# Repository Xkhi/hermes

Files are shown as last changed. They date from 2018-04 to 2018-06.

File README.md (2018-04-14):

# Project Hermes 

Property of [Waseda University](https://www.waseda.jp/top/en) [Graduate School of Creative Science and Engineering](http://www.cse.sci.waseda.ac.jp/en/).
Developed by [Javier Alvarez](mailto:javier.alvarez@akane.waseda.jp).

Project Hermes is a communication hub for sensors, developed specifically for WU's Sensor Team in Sugano Lab. 

## Status
- [x] Requirements definition
- [x] Conceptual design
- [x] Schematics
- [x] PCB
- [ ] Manufacture
- [ ] Programming

### Status Overview
The project has finished establishing requirements, concepts and schematics, and the PCB layout design has finished. The manufacturing process will begin soon.

## Specifications
The aim for the device are listed as follows:

* Act as a communication HUB for 5 sensors (I<sup>2</sup>C)
* Provide a network for communication between devices by a common bus (I<sup>2</sup>C)
* Power input 5V~12V

## Contact

For questions regarding the device:

* Design: [Javier Alvarez](mailto:javier.alvarez@akane.waseda.jp)
* Ownership: [Alexander Schmitz](mailto:schmitz.alexander@gmail.com), [Tito Tomo](mailto:tito@toki.waseda.jp), [Sophon Somlor](mailto:sophon@sugano.mech.waseda.ac.jp)

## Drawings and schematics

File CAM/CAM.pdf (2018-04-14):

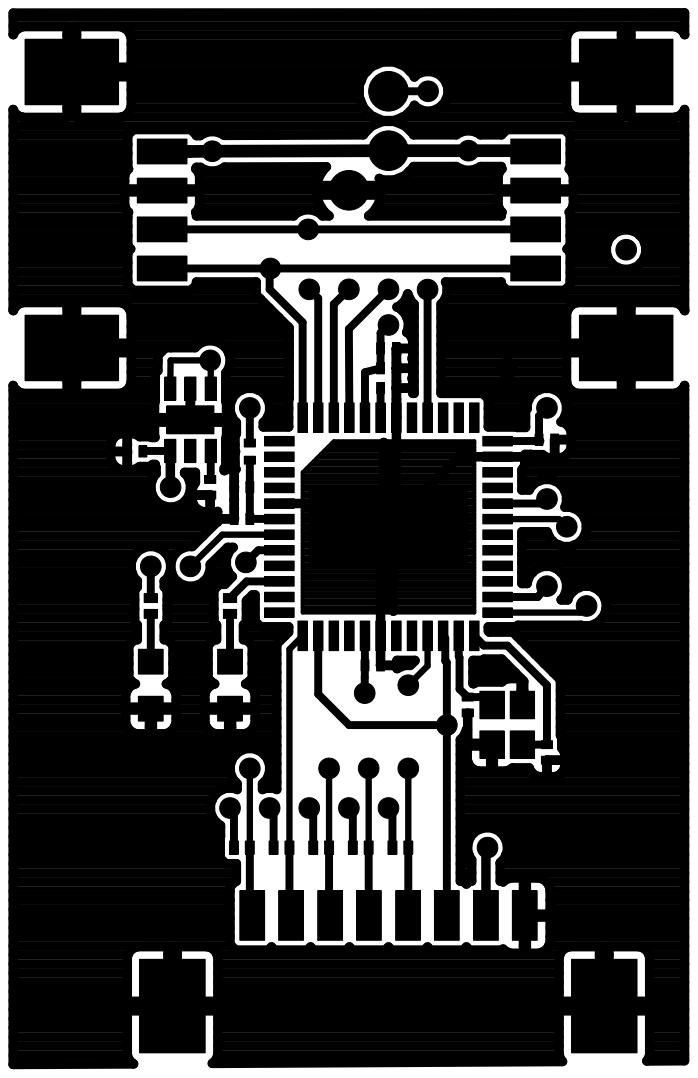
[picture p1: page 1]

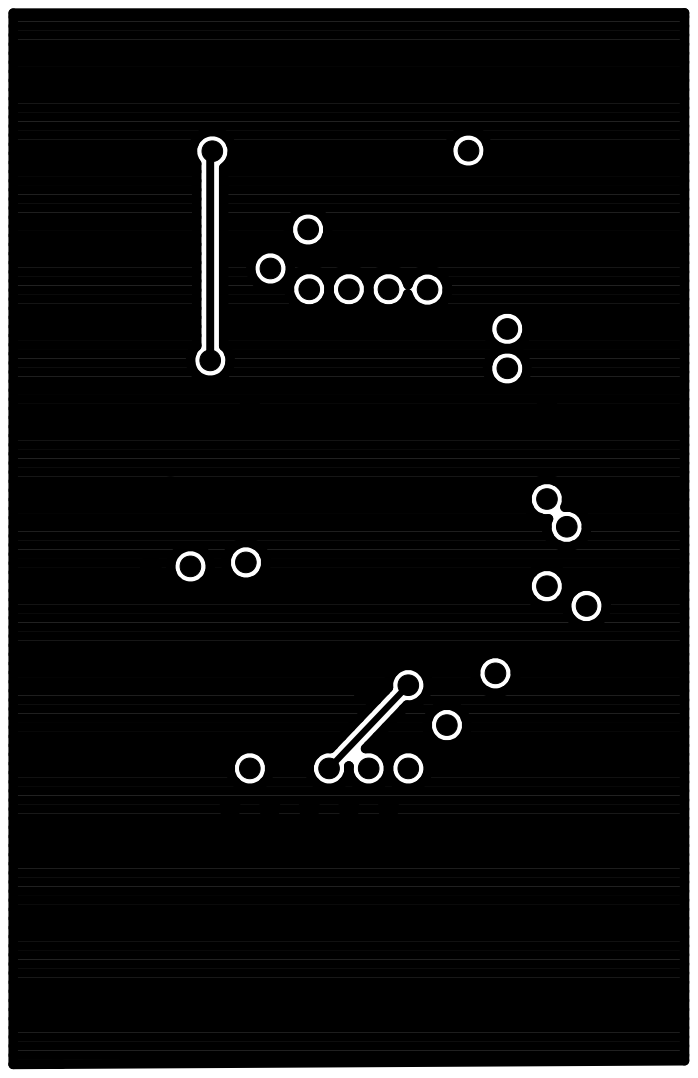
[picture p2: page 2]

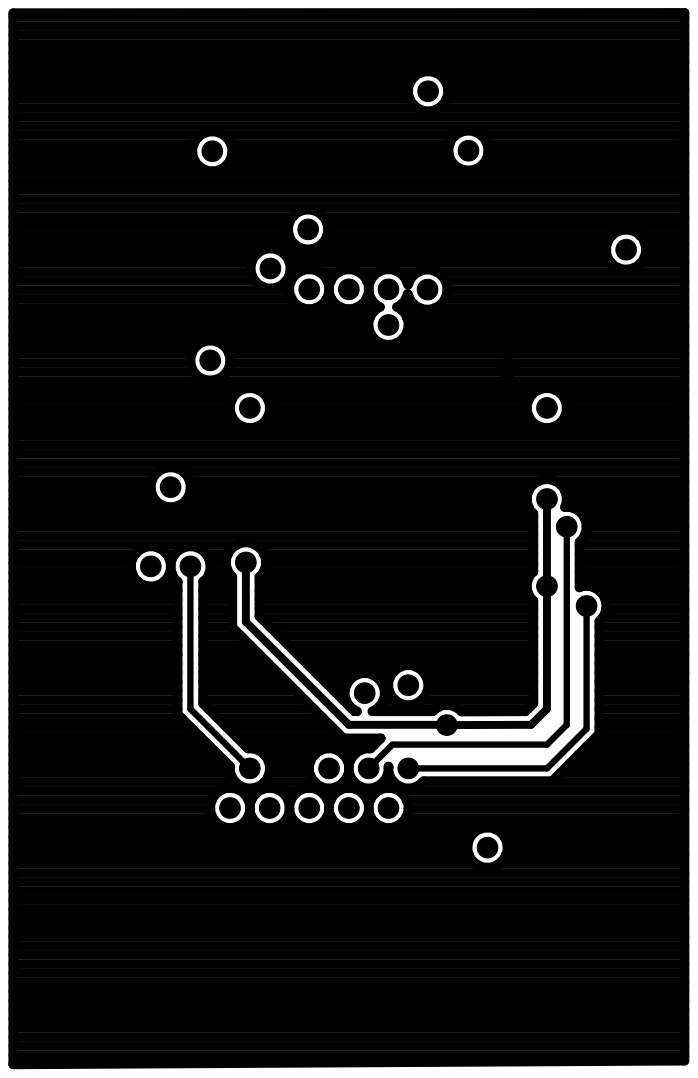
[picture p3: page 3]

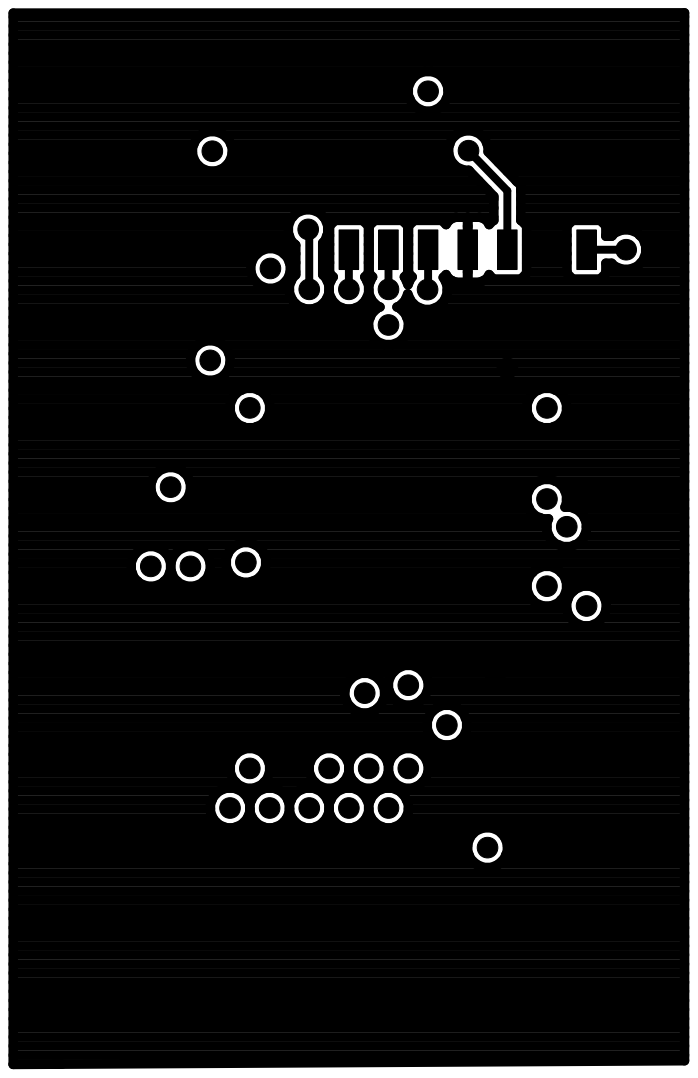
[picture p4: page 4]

# 3V3 GND

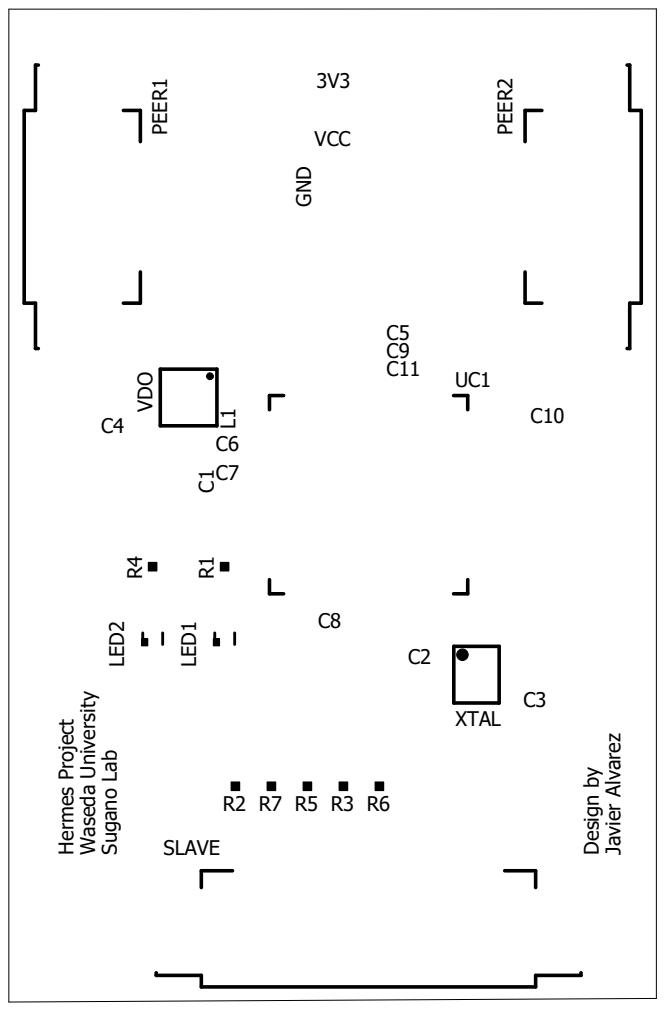
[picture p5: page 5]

Hermes Project Waseda University Sugano Lab Design by Javier Alvarez C1

PIN3 PIN4 PIN5 PIN6 PIN1 PIN2

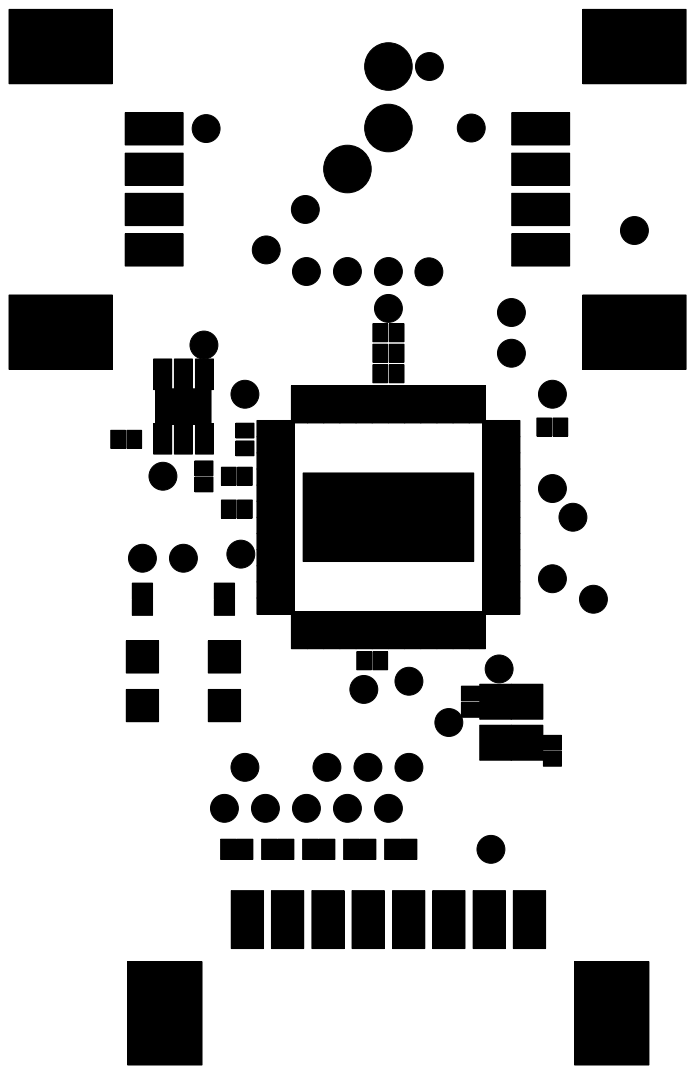
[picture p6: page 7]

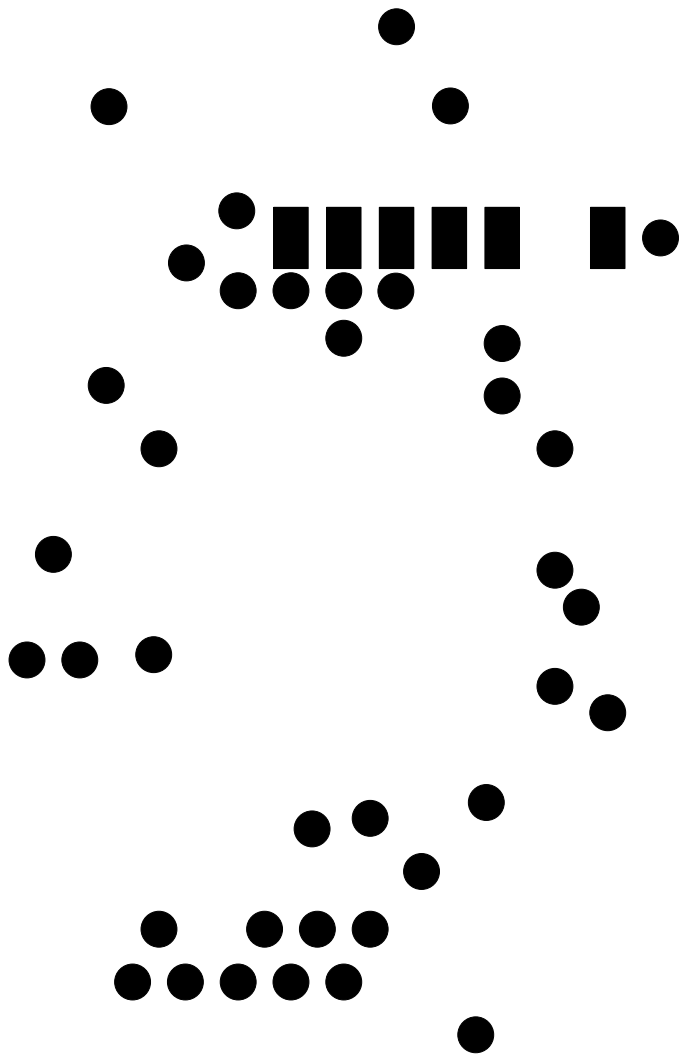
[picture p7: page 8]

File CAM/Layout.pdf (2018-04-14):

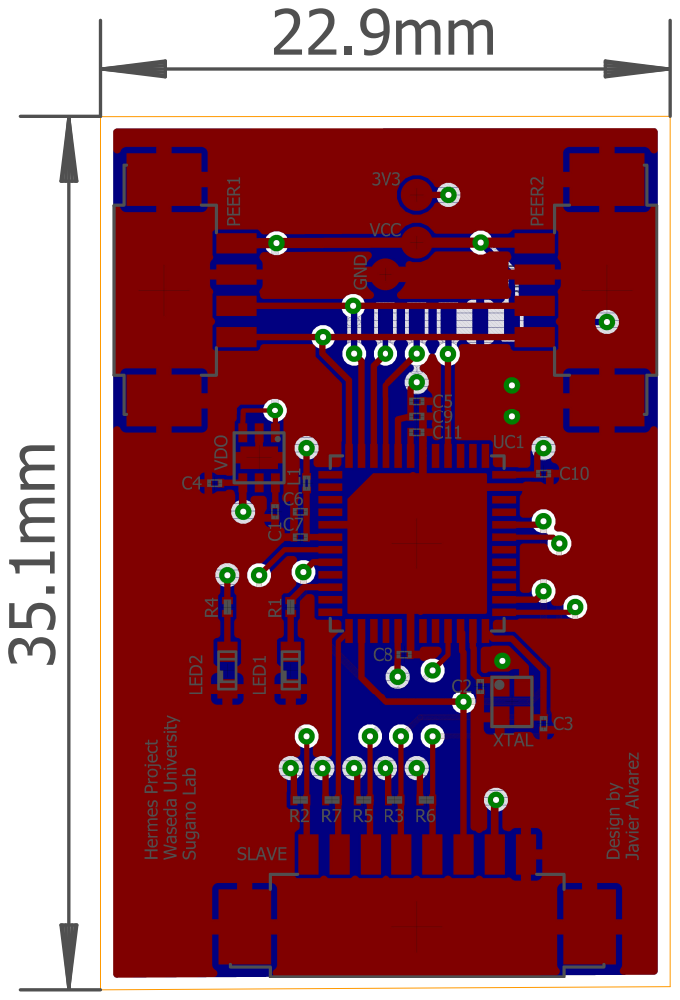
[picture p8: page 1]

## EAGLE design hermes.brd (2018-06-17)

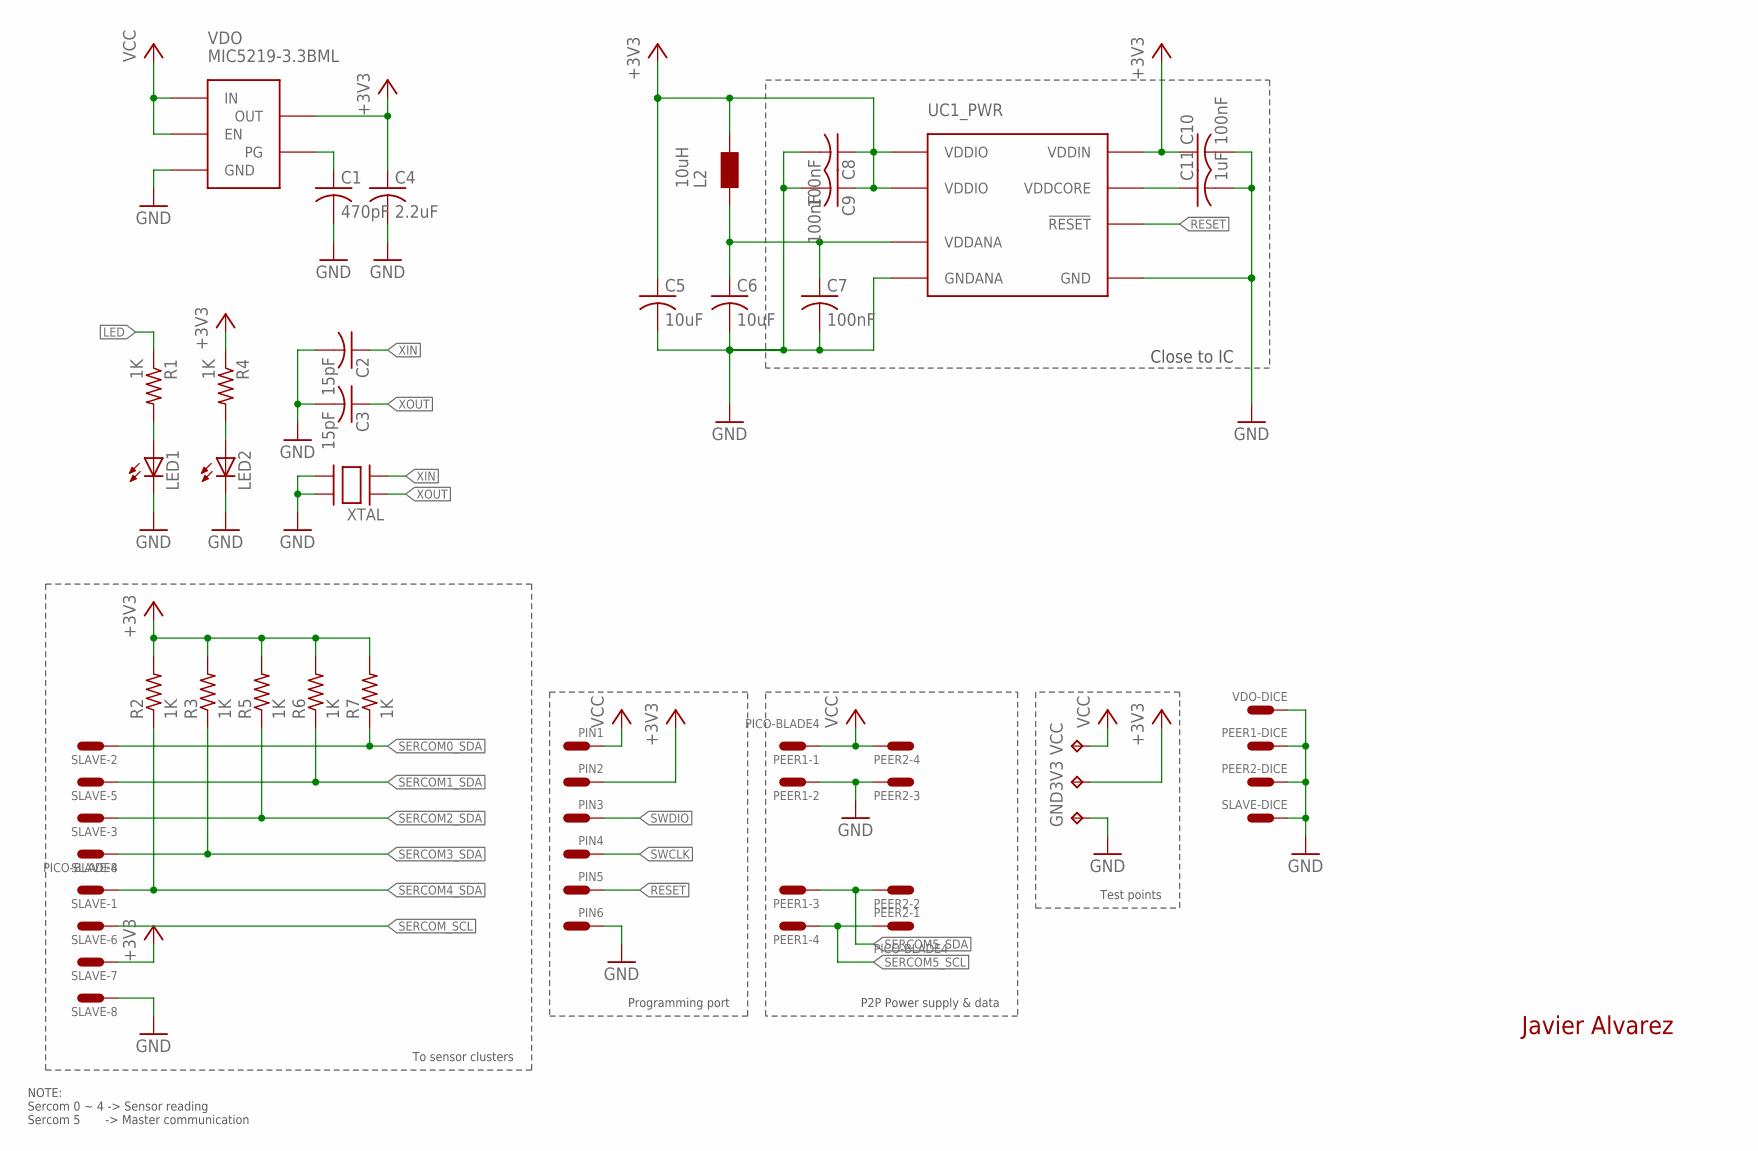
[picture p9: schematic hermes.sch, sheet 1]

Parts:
3V3: TPB1,27; B1,27
C1: 470pF; C0201
C2, C3: 15pF; C0201
C4: 2.2uF; C0201
C5, C6: 10uF; C0402
C7, C8, C9, C10: 100nF; C0201
C11: 1uF; C0201
GND: TPB1,27; B1,27
L2: 10uH; L2215
LED1, LED2: LED_ESML0603; LED_SML0603
PEER1, PEER2: PICO-BLADE4
PIN1, PIN2, PIN3, PIN4, PIN5, PIN6: SINGLE-PIN; PAD5025
R1, R2, R3, R4, R5, R6, R7: 1K; R0201
SLAVE: PICO-BLADE8
UC1: ATSAMD20G-QFN48; QFN-48
VCC: TPB1,27; B1,27
VDO: MIC5219-3.3BML; MLF-6
XTAL: LFXTAL059596CUTT; 2X1.6

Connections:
!RESET: PIN5.P$1, UC1.P$40 (!RESET)
+3V3: 3V3.TP, C4.1, C5.1, C8.1, C9.1, C10.1, L2.P$2, PIN2.P$1, R2.2, R3.2, R4.1, R5.2, R6.2, R7.2, SLAVE.P$9, UC1.P$17 (VDDIO), UC1.P$36 (VDDIO), UC1.P$44 (VDDIN), VDO.P$4 (OUT)
GND: C1.2, C2.2, C3.2, C4.2, C5.2, C6.2, C7.2, C8.2, C9.2, C10.2, C11.2, GND.TP, LED1.C, LED2.C, PEER1.P$1, PEER1.P$2, PEER1.P$4, PEER2.P$1, PEER2.P$2, PEER2.P$5, PIN6.P$1, SLAVE.P$1, SLAVE.P$2, SLAVE.P$10, UC1.P$5 (GNDANA), UC1.P$18 (GND), UC1.P$35 (GND), UC1.P$42 (GND), UC1.P$49 (GND), VDO.P$2 (GND), VDO.P$7, XTAL.GND@1 (GND), XTAL.GND@2 (GND)
LED: R1.1; also elsewhere on the board
unnamed: C6.1, C7.1, L2.P$1, UC1.P$6 (VDDANA)
unnamed: C1.1, VDO.P$6 (PG)
unnamed: C11.1, UC1.P$43 (VDDCORE)
unnamed: LED1.A, R1.2
unnamed: LED2.A, R4.2
SERCOM0_SDA: R7.1, SLAVE.P$4; also elsewhere on the board
SERCOM1_SDA: R6.1, SLAVE.P$7; also elsewhere on the board
SERCOM2_SDA: R5.1, SLAVE.P$5; also elsewhere on the board
SERCOM3_SDA: R3.1, SLAVE.P$6; also elsewhere on the board
SERCOM4_SDA: R2.1, SLAVE.P$3; also elsewhere on the board
SERCOM5_SCL: PEER1.P$6, PEER2.P$3; also elsewhere on the board
SERCOM5_SDA: PEER1.P$5, PEER2.P$4; also elsewhere on the board
SERCOM_SCL: SLAVE.P$8; also elsewhere on the board
SWCLK: PIN4.P$1; also elsewhere on the board
SWDIO: PIN3.P$1; also elsewhere on the board
VCC: PEER1.P$3, PEER2.P$6, PIN1.P$1, VCC.TP, VDO.P$1 (EN), VDO.P$3 (IN)
XIN: C2.1, XTAL.XTAL@1 (XTAL); also elsewhere on the board
XOUT: C3.1, XTAL.XTAL@2 (XTAL); also elsewhere on the board

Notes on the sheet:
Close to IC
Javier Alvarez
NOTE: Sercom 0 ~ 4 -> Sensor reading Sercom 5 -> Master communication
To sensor clusters
Programming port
P2P Power supply & data
Test points

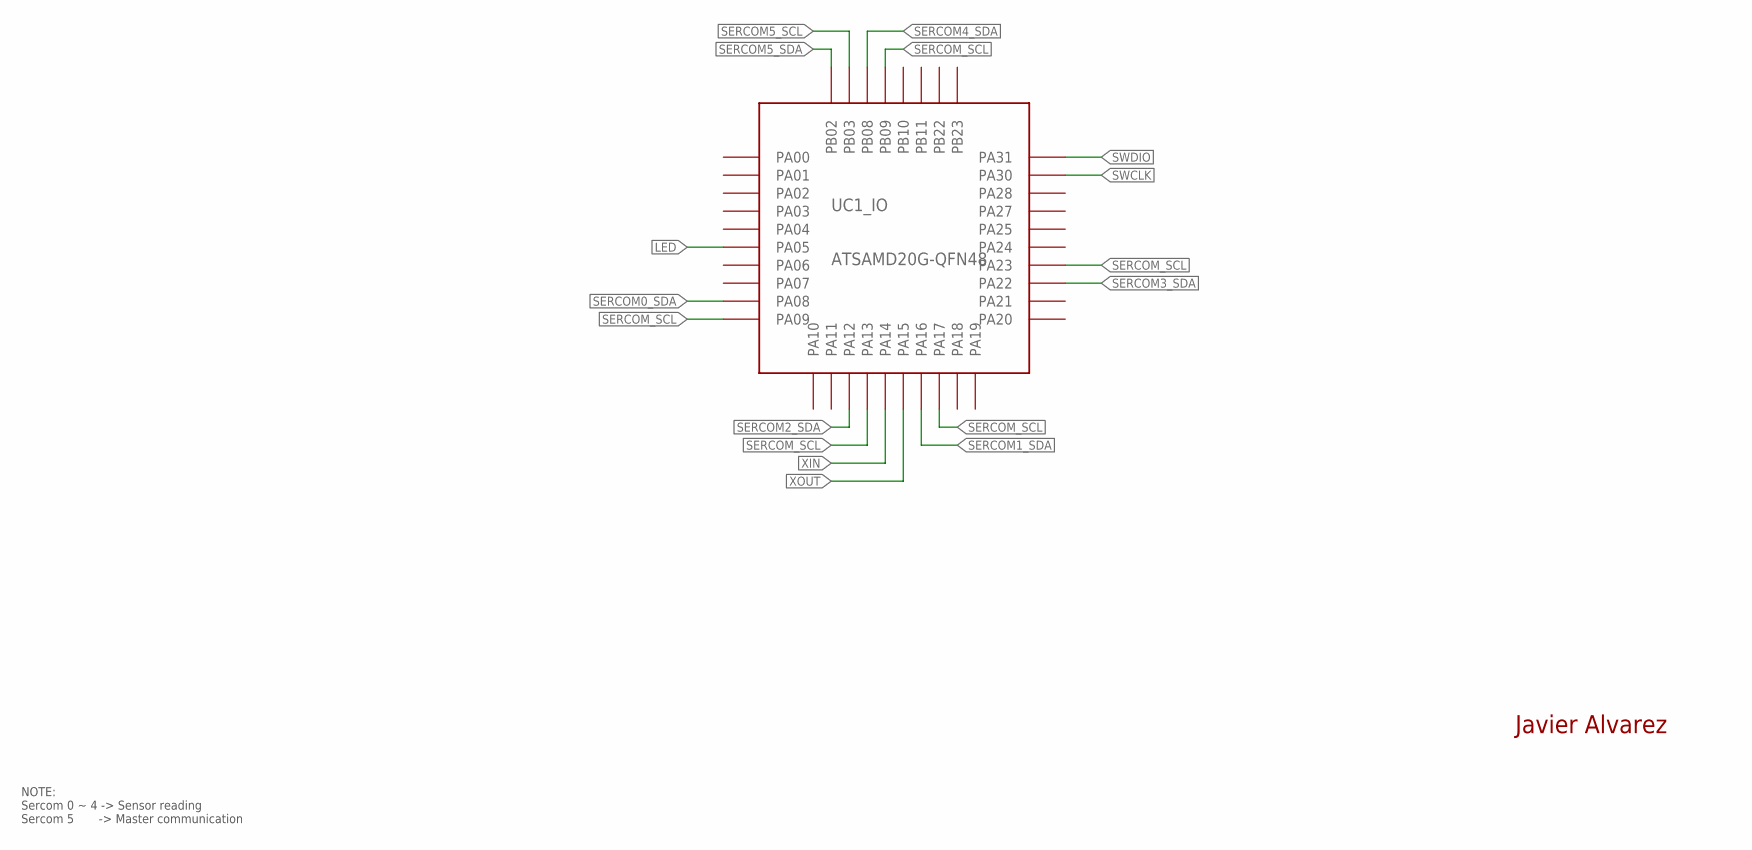
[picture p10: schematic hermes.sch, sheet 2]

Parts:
UC1: ATSAMD20G-QFN48; QFN-48

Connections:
LED: UC1.P$10 (PA05); also elsewhere on the board
SERCOM0_SDA: UC1.P$13 (PA08); also elsewhere on the board
SERCOM1_SDA: UC1.P$25 (PA16); also elsewhere on the board
SERCOM2_SDA: UC1.P$21 (PA12); also elsewhere on the board
SERCOM3_SDA: UC1.P$31 (PA22); also elsewhere on the board
SERCOM4_SDA: UC1.P$7 (PB08); also elsewhere on the board
SERCOM5_SCL: UC1.P$48 (PB03); also elsewhere on the board
SERCOM5_SDA: UC1.P$47 (PB02); also elsewhere on the board
SERCOM_SCL: UC1.P$8 (PB09), UC1.P$14 (PA09), UC1.P$22 (PA13), UC1.P$26 (PA17), UC1.P$32 (PA23); also elsewhere on the board
SWCLK: UC1.P$45 (PA30); also elsewhere on the board
SWDIO: UC1.P$46 (PA31); also elsewhere on the board
XIN: UC1.P$23 (PA14); also elsewhere on the board
XOUT: UC1.P$24 (PA15); also elsewhere on the board

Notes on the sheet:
Javier Alvarez
NOTE: Sercom 0 ~ 4 -> Sensor reading Sercom 5 -> Master communication

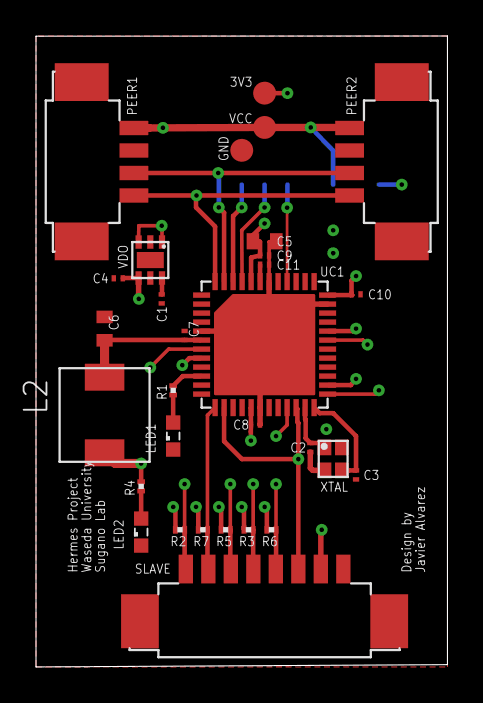
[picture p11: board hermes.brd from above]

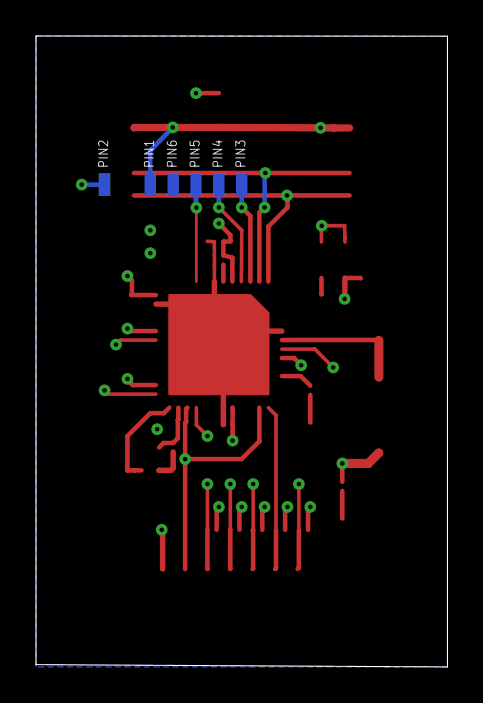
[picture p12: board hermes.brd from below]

Board: 4 copper layers, 22.9 x 35.1 mm, 36 parts (6 on the bottom side), 22 nets.

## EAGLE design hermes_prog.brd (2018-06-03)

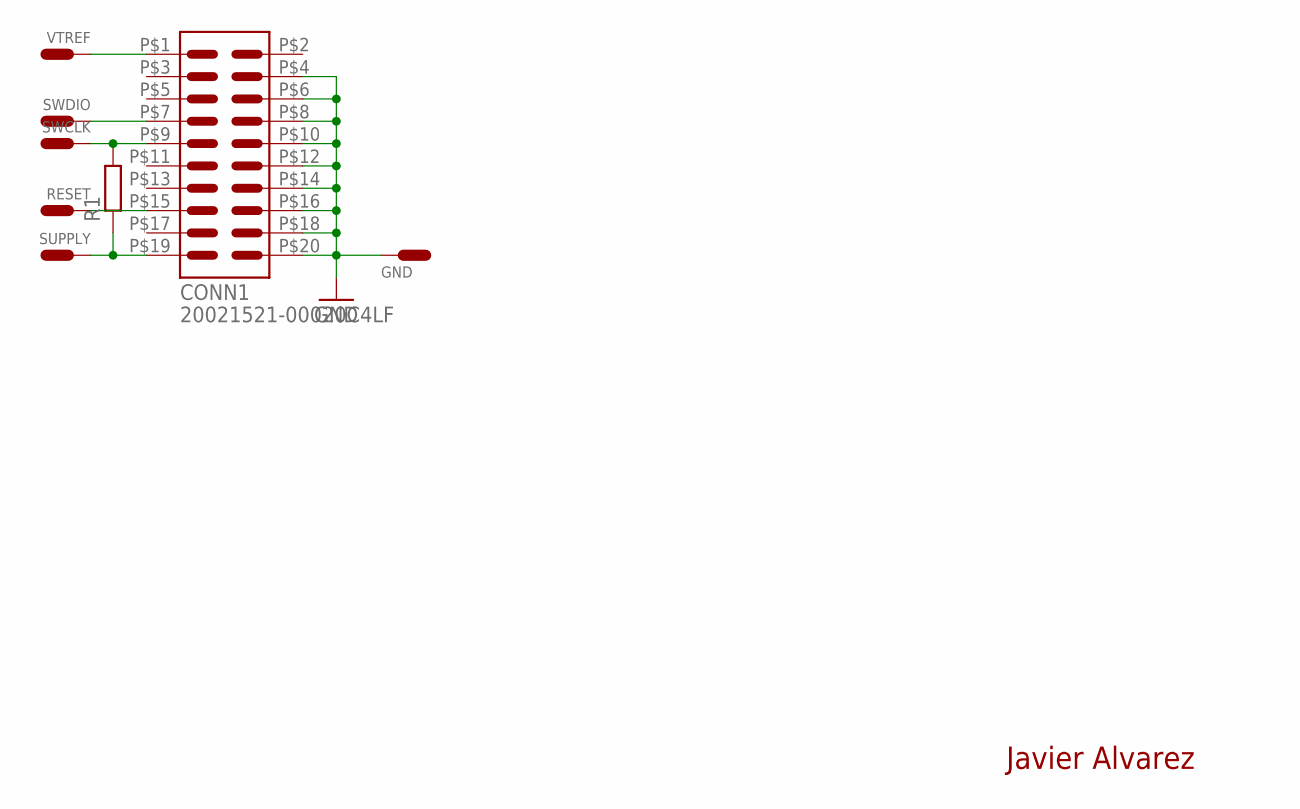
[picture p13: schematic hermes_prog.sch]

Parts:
CONN1: 20021521-00020C4LF; JTAG-20
GND: S7231-45R; SPRING-CONTACT
R1: R-EU_0204/2V; 0204V
RESET: S7231-45R; SPRING-CONTACT
SUPPLY: S7231-45R; SPRING-CONTACT
SWCLK: S7231-45R; SPRING-CONTACT
SWDIO: S7231-45R; SPRING-CONTACT
VTREF: S7231-45R; SPRING-CONTACT

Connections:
GND: CONN1.P$4, CONN1.P$6, CONN1.P$8, CONN1.P$10, CONN1.P$12, CONN1.P$14, CONN1.P$16, CONN1.P$18, CONN1.P$20, GND.P$1, GND.P$2
RESET: CONN1.P$15, RESET.P$1, RESET.P$2
SUPPLY: CONN1.P$19, R1.1, SUPPLY.P$1, SUPPLY.P$2
SWCLK: CONN1.P$9, R1.2, SWCLK.P$1, SWCLK.P$2
SWDIO: CONN1.P$7, SWDIO.P$1, SWDIO.P$2
VTREF: CONN1.P$1, VTREF.P$1, VTREF.P$2

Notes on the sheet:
Javier Alvarez

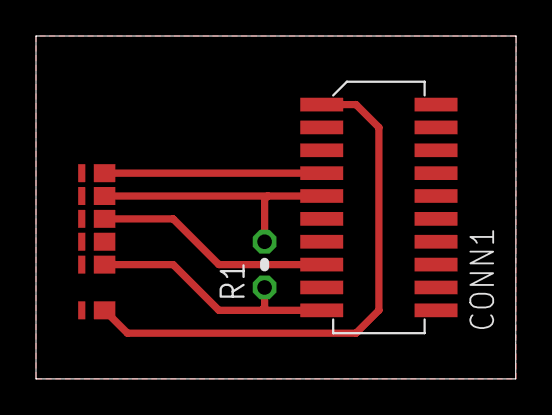
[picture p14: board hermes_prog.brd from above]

Board: 2 copper layers, 26.7 x 19.1 mm, 8 parts (0 on the bottom side), 6 nets.

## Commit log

2017-12-15 Initial commit, shcematics only
    [hermes.sch]
2017-12-17 -Add LDO -Add library -Notes to uC PWR
    [hermes.sch]
2017-12-21 -SCH: Add placeholders for XTAL and LED -LBR: Add symbolic connection
    [hermes.sch]
2017-12-23 -Add I2C placeholders
    [hermes.sch]
2018-01-06 -Add XTAL to library -Add LDO to library -Add XTAL and LDO to schematics -Update .gitignore to ignore additional library files -Fix minor design flaws -Fix minor value errors in capacitance
    [hermes.sch]
2018-01-07 -Remove Reset switch -Add programming port -Correct minor connection issues
    [hermes.sch]
2018-01-14 -Correct README.md specifications -Add custom pads to library -Add programming connection to schematics
    [hermes.sch]
2018-01-21 -Confirm cabling -Add information
    [hermes.sch]
2018-02-17 -Add correct connectors to library and board
    [hermes.sch]
2018-02-17 -Start layout board
    [hermes.brd]
2018-02-18 -Update Library -Correct P2P pins -Place general position of components
    [hermes.brd, hermes.sch]
2018-03-11 -General routing
    [hermes.brd]
2018-03-25 MIniaturization of board process
    [hermes.brd, hermes.sch]
2018-04-01 Reduction of board (Cont'd)
    [hermes.brd]
2018-04-14 First release of Hermes, Add Layout view and CAM files, Correct minor issues
    [hermes.brd, hermes.sch]
2018-04-14 First release of Hermes, Add Layout view and CAM files, Add Bill of Materials (BOM), Correct minor issues
2018-05-27 Add elements for programmer to library and programmer schematics
    [hermes_prog.sch]
2018-06-03 Add programming board to design
    [hermes_prog.brd]
2018-06-17 Replace components according to availability in digital stores (Capacitors and Inductors)
    [hermes.brd, hermes.sch]
